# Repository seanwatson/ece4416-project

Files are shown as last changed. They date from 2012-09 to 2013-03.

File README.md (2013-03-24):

Engineering 4th Year Design Project:
====================================
Wireless Control System Utilizing Head Movement
===============================================

Description
-----------

As part of the engineering degree program at The University of Western Ontario
all students must complete an eight month design project in their final year
of study. For my project I developed a wireless control system that utilizes
head movement as the input to the system. The goal was to improve accessibility
for patients with limited or no control of their limbs.

For demonstration purposes the device was designed to control the movement and
clicking of a mouse on a computer screen. The device consists of a small,
wearable circuit that is concealed within a baseball cap and software running
on the computer. When the device is within wireless range of the computer it
automatically connects with the computer over bluetooth and
begins translating the user's head motions into mouse movements and clicks on the
screen.

For more information regarding the hardware designs please refer to the "hardware"
directory.

For more information regarding the software please refer to the "software"
directory.

Licenses
--------

The hardware designs in this work are licensed under a Creative Commons Attribution
3.0 license. The software in this work is licensed under the MIT license. Please refer
to the individual hardware and software directories for more information.

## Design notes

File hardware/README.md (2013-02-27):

Hardware
========

Overview
--------

The hardware consists of a microcontroller, a bluetooth module, an accelerometer, and power management circuitry:

###Microcontroller

- Atmel ATMega32U4
- Programming and debugging over USB port
- UART, ADC
- Deep sleep for power saving

###Bluetooth Module

- Roving Networks RN-42
- Communicates with MCU over UART
- Low power connect, SNIFF mode for power saving

###Accelerometer

- Analog Devices ADP3338
- 3 axis, analog outputs
- Very low power

###Power Management

- 850mA LiPo battery
- 3.3V linear regulator
- LiPo charge controller on board
- Charges over USB

Revisions
---------

The hardware for this project was developed over two revisions:

###Revision 1
- Designed as a development and debugging board for the purpose of easily diagnosing and fixing any bugs.
- Larger parts
- Debugging LEDs
- Debugging jumpers, etc. for the purpose of easily diagnosing and fixing any bugs.

###Revision 2
- Stripped down version of the circuit
- Lower power consumption
- Smaller physical size
- Smaller parts and no debugging features
- Can be concealed within a baseball cap

License
-------

These designs are licensed under a Creative Commons Attribution 3.0 license. See the
LICENSE.txt file for more details.

Acknowledgements
----------------

I'd like to thank the following companies who provided free or discount products and/or services
as part of this school project:

- Alberta Printed Circuits
- Analog Devices
- Atmel
- Microchip
- Roving Networks

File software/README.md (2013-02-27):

Software
=======

Overview
-------------

I have divided the software for this project into client and embedded software:

###Client

- Runs on the user's computer
- Searches for the device
- Automatically connects to the device when it was found
- Translates received commands into mouse movements and clicks on the screen

###Embedded

- Software running on the remote device
- Puts the device into a sleep state until a connection is found
- Once connected it continutally takes accelerometer readings
- Processes the accelerometer readings to determine motions
- Transmits the detected motions to the computer over bluetooth

Please refer to the individual "client" and "embedded" directories for more information.

License
-------------

The software for this work is licensed under an MIT license. Please refer to LICENSE.md for more details.

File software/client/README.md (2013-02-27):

Client
====

Files
-------

- **ece4416-project.py** - The main application for this project
- **bluetooth_connection.py** - Manages the bluetooth communication between the computer and the device
- **motion_handler.py** - Translates the received "motion codes" into mouse movements and clicks
- **motion.py** - Different motions that can be detected by the device
- **mouse_movement.py** - Different mouse actions that can be preformed when a motion is detected

Dependencies
-------------

- python-pybluez (bluetooth socket handling)
- python-pymouse (mouse movement and clicking)

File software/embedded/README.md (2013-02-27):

Embedded
====

Files
-------

- **ece4416_embedded** - The main embedded code
- **libraries** - Additional code for the project to help with accelerometer and motion handling. See the directory for information about the individual libraries
- **bluetooth_loader** - A program that quickly configures the bluetooth module to the settings used by this project
- **eeprom_loader** - Loads the EEPROM with known calibration values
- **serial_forwarder** - Forwards serial data from bluetooth to USB and USB to bluetooth. Used for debugging
- **accel_tester** - Used to print a stream of accelerometer readings to the screen. Used for debugging
- **comm\_handler\_test** - Program for testing the functionality of the communication handler

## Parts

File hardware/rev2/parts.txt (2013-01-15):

Partlist

Exported from sw-4416-project-v2.sch at 13-01-15 9:42 AM

EAGLE Version 6.2.0 Copyright (c) 1988-2012 CadSoft

Assembly variant: 

Part     Value                    Device                   Package             Library    Sheet

C1       0.1u                     CAP0603-CAP              0603-CAP            SparkFun   1
C2       0.1u                     CAP0603-CAP              0603-CAP            SparkFun   1
C3       0.1u                     CAP0603-CAP              0603-CAP            SparkFun   1
C4       1u                       CAP0603-CAP              0603-CAP            SparkFun   1
C5       1u                       CAP0603-CAP              0603-CAP            SparkFun   1
C6       22p                      CAP0603-CAP              0603-CAP            SparkFun   1
C7       22p                      CAP0603-CAP              0603-CAP            SparkFun   1
C8       4.7u                     CAP0603-CAP              0603-CAP            SparkFun   1
C9       4.7u                     CAP0603-CAP              0603-CAP            SparkFun   1
C10      4.7u                     CAP0603-CAP              0603-CAP            SparkFun   1
J1       CON_HEADER_PRG_AVR_ICSP" CON_HEADER_PRG_AVR_ICSP" HEADER_PRG_2X03_SMD dp_devices 1
JP1                               JUMPER-2PTH              1X02                SparkFun   1
L1                                INDUCTOR0805             0805                SparkFun   1
LED1                              LED0603                  LED-0603            SparkFun   1
R1       22                       RESISTOR0603-RES         0603-RES            SparkFun   1
R2       22                       RESISTOR0603-RES         0603-RES            SparkFun   1
R3       2k                       RESISTOR0603-RES         0603-RES            SparkFun   1
R4       10k                      RESISTOR0603-RES         0603-RES            SparkFun   1
R5       1M                       RESISTOR0603-RES         0603-RES            SparkFun   1
R6       330                      RESISTOR0603-RES         0603-RES            SparkFun   1
S1                                SWITCH-SPST-SMD-A        SWITCH-SPST-SMD-A   SparkFun   1
U$1      ATMEGA32U4QFN            ATMEGA32U4QFN            QFN-44              SparkFun   1
U$2      BLUETOOTH-RN41"          BLUETOOTH-RN41"          RN41                SparkFun   1
U$3      CRYSTAL_SMT              CRYSTAL_SMT              CRYSTAL-SMD-5X3     SparkFun   1
U1       ADXL335                  ADXL335                  LFCSP-16            SparkFun   1
U2       MCP73831                 MCP73831                 SOT23-5             SparkFun   1
VREG1    ADP3338                  VREG_3PINS-SOT-223       SOT-223             dp_devices 1
X1       USB-MICROB               USB-MICROB               USB-MICROB          SparkFun   1

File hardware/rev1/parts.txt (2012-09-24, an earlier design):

Partlist

Exported from sw-4416-project-v1.sch at 12-09-24 6:30 PM

EAGLE Version 6.2.0 Copyright (c) 1988-2012 CadSoft

Assembly variant: 

Part     Value           Device             Package           Library    Sheet

C1       0.1uF           CAP0603-CAP        0603-CAP          SparkFun   1
C2       0.1uF           CAP0603-CAP        0603-CAP          SparkFun   1
C3       0.1uF           CAP0603-CAP        0603-CAP          SparkFun   1
C4       4.7uF           CAP0603-CAP        0603-CAP          SparkFun   1
C5       4.7uF           CAP0603-CAP        0603-CAP          SparkFun   1
C6       4.7uF           CAP0603-CAP        0603-CAP          SparkFun   1
C7       4.7uF           CAP0603-CAP        0603-CAP          SparkFun   1
C8       4.7uF           CAP0603-CAP        0603-CAP          SparkFun   1
C9       4.7uF           CAP0603-CAP        0603-CAP          SparkFun   1
C10      22pF            CAP0603-CAP        0603-CAP          SparkFun   1
C11      22pF            CAP0603-CAP        0603-CAP          SparkFun   1
C12      1uF             CAP0603-CAP        0603-CAP          SparkFun   1
C13      1uF             CAP0603-CAP        0603-CAP          SparkFun   1
CN1                      JST_2PIN-SMT-RA    JST-PH-2-SMT-RA   adafruit   1
IC1      MCP73831        MCP73831           SOT23-5           SparkFun   1
ISP1     AVRISP-6        AVRISP-6           AVRISP            adafruit   1
JP1      Vcc             JUMPER-2PTH        1X02              SparkFun   1
JP2      VUSB            JUMPER-2PTH        1X02              SparkFun   1
JP3      3.3V            JUMPER-2PTH        1X02              SparkFun   1
JP4      GND             JUMPER-2PTH        1X02              SparkFun   1
JP5      AREF            JUMPER-2PTH        1X02              SparkFun   1
JP6      UART            JUMPER-2PTH        1X02              SparkFun   1
JP7      USB             JUMPER-2PTH        1X02              SparkFun   1
JP8      JUMPER-3PTH     JUMPER-3PTH        1X03              SparkFun   1
L1                       INDUCTOR0805       0805              SparkFun   1
LED1     Red             LED0603            LED-0603          SparkFun   1
LED2     Green           LED0603            LED-0603          SparkFun   1
LED3     Green           LED0603            LED-0603          SparkFun   1
LED4     Power           LED0603            LED-0603          SparkFun   1
LED5     RX              LED0603            LED-0603          SparkFun   1
LED6     TX              LED0603            LED-0603          SparkFun   1
LED7     DBG0            LED0603            LED-0603          SparkFun   1
LED8     DBG1            LED0603            LED-0603          SparkFun   1
R1       330             RESISTOR0603-RES   0603-RES          SparkFun   1
R2       10K             RESISTOR0603-RES   0603-RES          SparkFun   1
R3       330             RESISTOR0603-RES   0603-RES          SparkFun   1
R4       2k              RESISTOR0603-RES   0603-RES          SparkFun   1
R5       330             RESISTOR0603-RES   0603-RES          SparkFun   1
R6       330             RESISTOR0603-RES   0603-RES          SparkFun   1
R7       330             RESISTOR0603-RES   0603-RES          SparkFun   1
R8       22              RESISTOR0603-RES   0603-RES          SparkFun   1
R9       22              RESISTOR0603-RES   0603-RES          SparkFun   1
R10      330             RESISTOR0603-RES   0603-RES          SparkFun   1
R11      1M              RESISTOR0603-RES   0603-RES          SparkFun   1
R12      10K             RESISTOR0603-RES   0603-RES          SparkFun   1
R13      10K             RESISTOR0603-RES   0603-RES          SparkFun   1
R14      10K             RESISTOR0603-RES   0603-RES          SparkFun   1
R15      330             RESISTOR0603-RES   0603-RES          SparkFun   1
R16      330             RESISTOR0603-RES   0603-RES          SparkFun   1
R17      10K             RESISTOR0603-RES   0603-RES          SparkFun   1
S1       Power           SWITCH-SPST-SMD-A  SWITCH-SPST-SMD-A SparkFun   1
U$1      ADXL335         ADXL335            LFCSP-16          SparkFun   1
U$2      ATMEGA32U4-AU   ATMEGA32U4-AU      TQFP44            adafruit   1
U$3      BLUETOOTH-RN41" BLUETOOTH-RN41"    RN41              SparkFun   1
U1       ADP3338         VREG_3PINS-SOT-223 SOT-223           dp_devices 1
X1       USB-MICROB      USB-MICROB         USB-MICROB        SparkFun   1
Y1       16M             CRYSTALHC49US      HC49US            SparkFun   1

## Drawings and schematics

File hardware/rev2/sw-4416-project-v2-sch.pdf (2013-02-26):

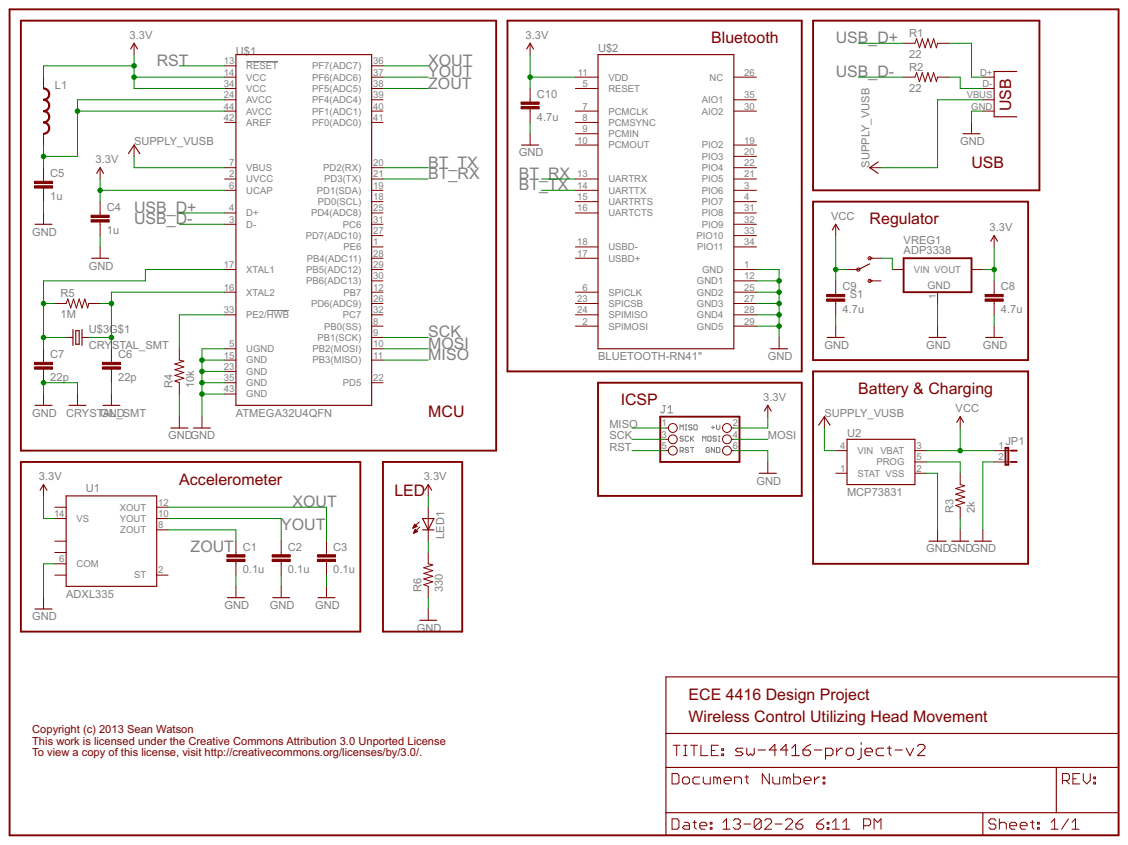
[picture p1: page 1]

ECE 4416 Design Project
Wireless Control Utilizing Head Movement

Copyright (c) 2013 Sean Watson This work is licensed under the Creative Commons Attribution 3.0 Unported License To view a copy of this license, visit http://creativecommons.org/licenses/by/3.0/.

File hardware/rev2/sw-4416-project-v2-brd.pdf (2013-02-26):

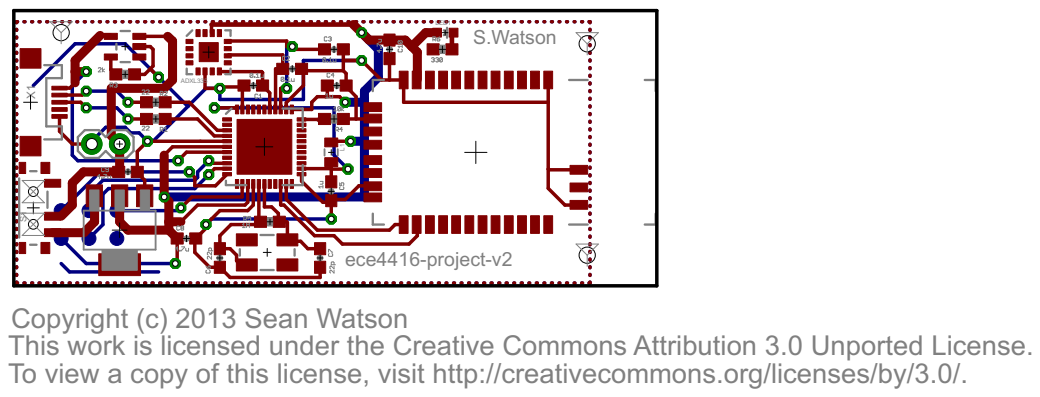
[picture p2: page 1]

Copyright (c) 2013 Sean Watson To view a copy of this license, visit http://creativecommons.org/licenses/by/3.0/. This work is licensed under the Creative Commons Attribution 3.0 Unported License.

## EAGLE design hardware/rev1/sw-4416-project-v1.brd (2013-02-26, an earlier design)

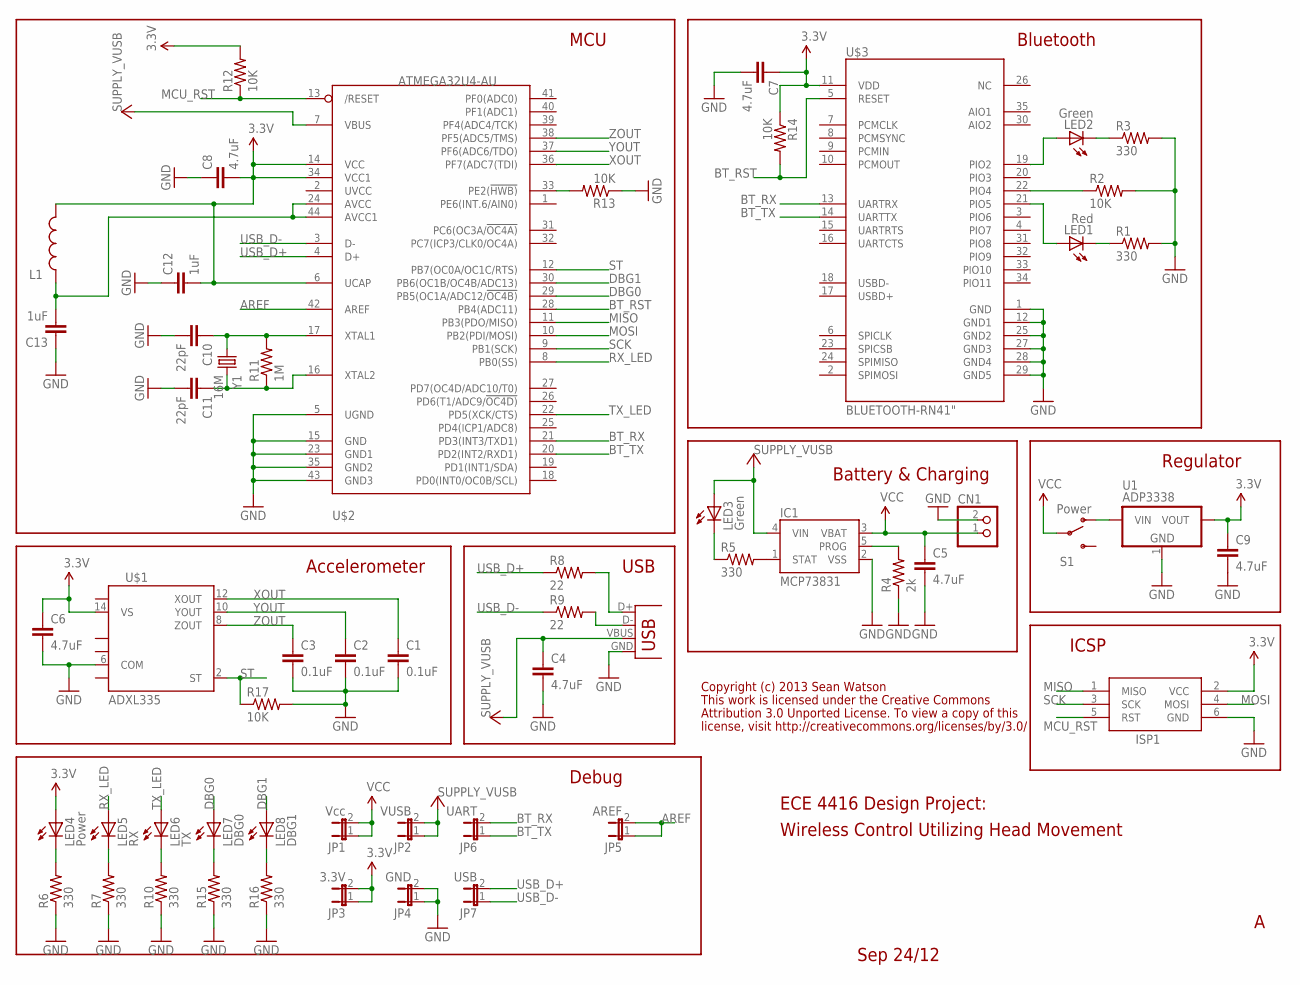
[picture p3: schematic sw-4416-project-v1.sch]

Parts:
C1, C2, C3: 0.1uF; 0603-CAP
C4, C5, C6, C7, C8, C9: 4.7uF; 0603-CAP
C10, C11: 22pF; 0603-CAP
C12, C13: 1uF; 0603-CAP
CN1: JST_2PIN-SMT-RA; JST-PH-2-SMT-RA
IC1: MCP73831; SOT23-5
ISP1: AVRISP-6; AVRISP
JP1: Vcc; 1X02
JP2: VUSB; 1X02
JP3: 3.3V; 1X02
JP4: GND; 1X02
JP5: AREF; 1X02
JP6: UART; 1X02
JP7: USB; 1X02
L1: INDUCTOR0805; 0805
LED1: Red; LED-0603
LED2, LED3: Green; LED-0603
LED4: Power; LED-0603
LED5: RX; LED-0603
LED6: TX; LED-0603
LED7: DBG0; LED-0603
LED8: DBG1; LED-0603
R1, R3, R5, R6, R7, R10, R15, R16: 330; 0603-RES
R2, R12, R13, R14, R17: 10K; 0603-RES
R4: 2k; 0603-RES
R8, R9: 22; 0603-RES
R11: 1M; 0603-RES
S1: Power; SWITCH-SPST-SMD-A
U1: ADP3338; SOT-223
U$1: ADXL335; LFCSP-16
U$2: ATMEGA32U4-AU; TQFP44
U$3: BLUETOOTH-RN41"; RN41
X1: USB-MICROB
Y1: 16M; HC49US

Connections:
3.3V: C6.1, C7.1, C8.2, C9.1, C12.2, ISP1.2 (VCC), JP3.1, JP3.2, L1.2, LED4.A, R12.2, R14.1, U1.2 (VOUT), U$1.14 (VS), U$2.6 (UCAP), U$2.14 (VCC), U$2.34 (VCC1), U$3.11 (VDD)
AREF: JP5.1, JP5.2, U$2.42 (AREF)
BT_RST: R14.2, U$2.28 (PB4(ADC11)), U$3.5 (RESET)
BT_RX: JP6.2, U$2.21 (PD3(INT3/TXD1)), U$3.13 (UARTRX)
BT_TX: JP6.1, U$2.20 (PD2(INT2/RXD1)), U$3.14 (UARTTX)
DBG0: LED7.A, U$2.29 (PB5(OC1A/ADC12/!OC4B))
DBG1: LED8.A, U$2.30 (PB6(OC1B/OC4B/ADC13))
GND: C1.2, C2.2, C3.2, C4.2, C5.2, C6.2, C7.2, C8.1, C9.2, C10.2, C11.2, C12.1, C13.1, CN1.2 (1), IC1.2 (VSS), ISP1.6 (GND), JP4.1, JP4.2, R1.2, R2.2, R3.2, R4.1, R6.1, R7.1, R10.1, R13.1, R15.1, R16.1, R17.2, U1.1 (GND), U$1.6 (COM), U$2.5 (UGND), U$2.15 (GND), U$2.23 (GND1), U$2.35 (GND2), U$2.43 (GND3), U$3.1 (GND), U$3.12 (GND1), U$3.25 (GND2), U$3.27 (GND3), U$3.28 (GND4), U$3.29 (GND5), X1.GND
MCU_RST: ISP1.5 (RST), R12.1, U$2.13 (/RESET)
MISO: ISP1.1 (MISO), U$2.11 (PB3(PDO/MISO))
MOSI: ISP1.4 (MOSI), U$2.10 (PB2(PDI/MOSI))
unnamed: LED2.C, R3.1
unnamed: LED1.C, R1.1
unnamed: R2.1, U$3.22 (PIO4)
unnamed: LED2.A, U$3.19 (PIO2)
unnamed: LED1.A, U$3.21 (PIO5)
unnamed: IC1.5 (PROG), R4.2
unnamed: IC1.1 (STAT), R5.2
unnamed: LED3.C, R5.1
unnamed: LED4.C, R6.2
unnamed: LED5.C, R7.2
unnamed: LED6.C, R10.2
unnamed: C10.1, R11.2, U$2.17 (XTAL1), Y1.1
unnamed: C11.1, R11.1, U$2.16 (XTAL2), Y1.2
unnamed: R8.2, X1.D+
unnamed: LED7.C, R15.2
unnamed: C13.2, L1.1, U$2.24 (AVCC), U$2.44 (AVCC1)
unnamed: LED8.C, R16.2
unnamed: R13.2, U$2.33 (PE2(!HWB))
unnamed: R9.2, X1.D-
RX_LED: LED5.A, U$2.8 (PB0(SS))
SCK: ISP1.3 (SCK), U$2.9 (PB1(SCK))
ST: R17.1, U$1.2 (ST), U$2.12 (PB7(OC0A/OC1C/RTS))
TX_LED: LED6.A, U$2.22 (PD5(XCK/CTS))
USB_D+: JP7.2, R8.1, U$2.4 (D+)
USB_D-: JP7.1, R9.1, U$2.3 (D-)
VCC: C5.1, CN1.1 (2), IC1.3 (VBAT), JP1.1, JP1.2, S1.2
VIN: S1.1 (O), U1.3 (VIN)
VUSB: C4.1, IC1.4 (VIN), JP2.1, JP2.2, LED3.A, U$2.7 (VBUS), X1.VBUS
XOUT: C1.1, U$1.12 (XOUT), U$2.36 (PF7(ADC7(TDI))
YOUT: C2.1, U$1.10 (YOUT), U$2.37 (PF6(ADC6/TDO))
ZOUT: C3.1, U$1.8 (ZOUT), U$2.38 (PF5(ADC5/TMS))

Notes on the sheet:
Accelerometer
Bluetooth
MCU
ECE 4416 Design Project:
Wireless Control Utilizing Head Movement
Battery & Charging
USB
Regulator
ICSP
Debug
Sep 24/12
Copyright (c) 2013 Sean Watson
This work is licensed under the Creative Commons
Attribution 3.0 Unported License. To view a copy of this
license, visit http://creativecommons.org/licenses/by/3.0/

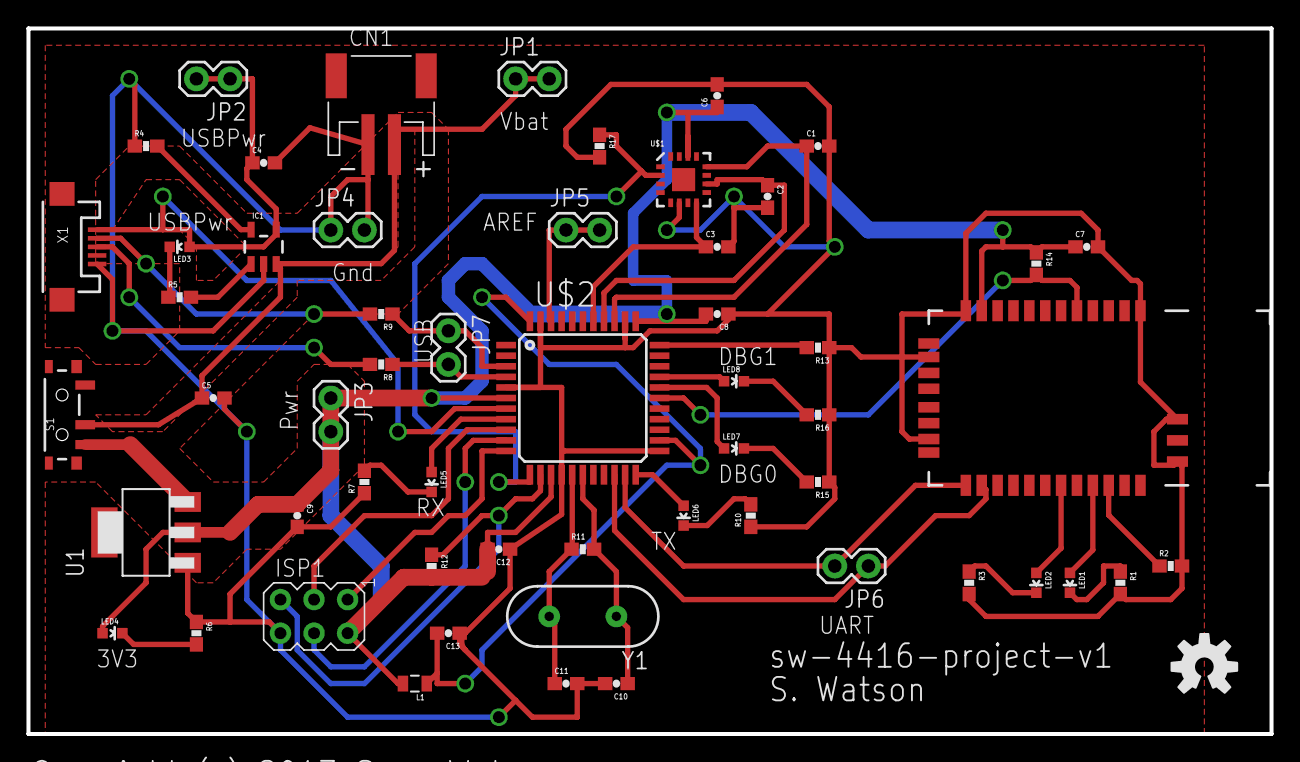
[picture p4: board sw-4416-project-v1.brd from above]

Board: 2 copper layers, 94.0 x 53.3 mm, 57 parts (0 on the bottom side), 42 nets.

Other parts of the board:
U$4: OSHW-LOGO-M

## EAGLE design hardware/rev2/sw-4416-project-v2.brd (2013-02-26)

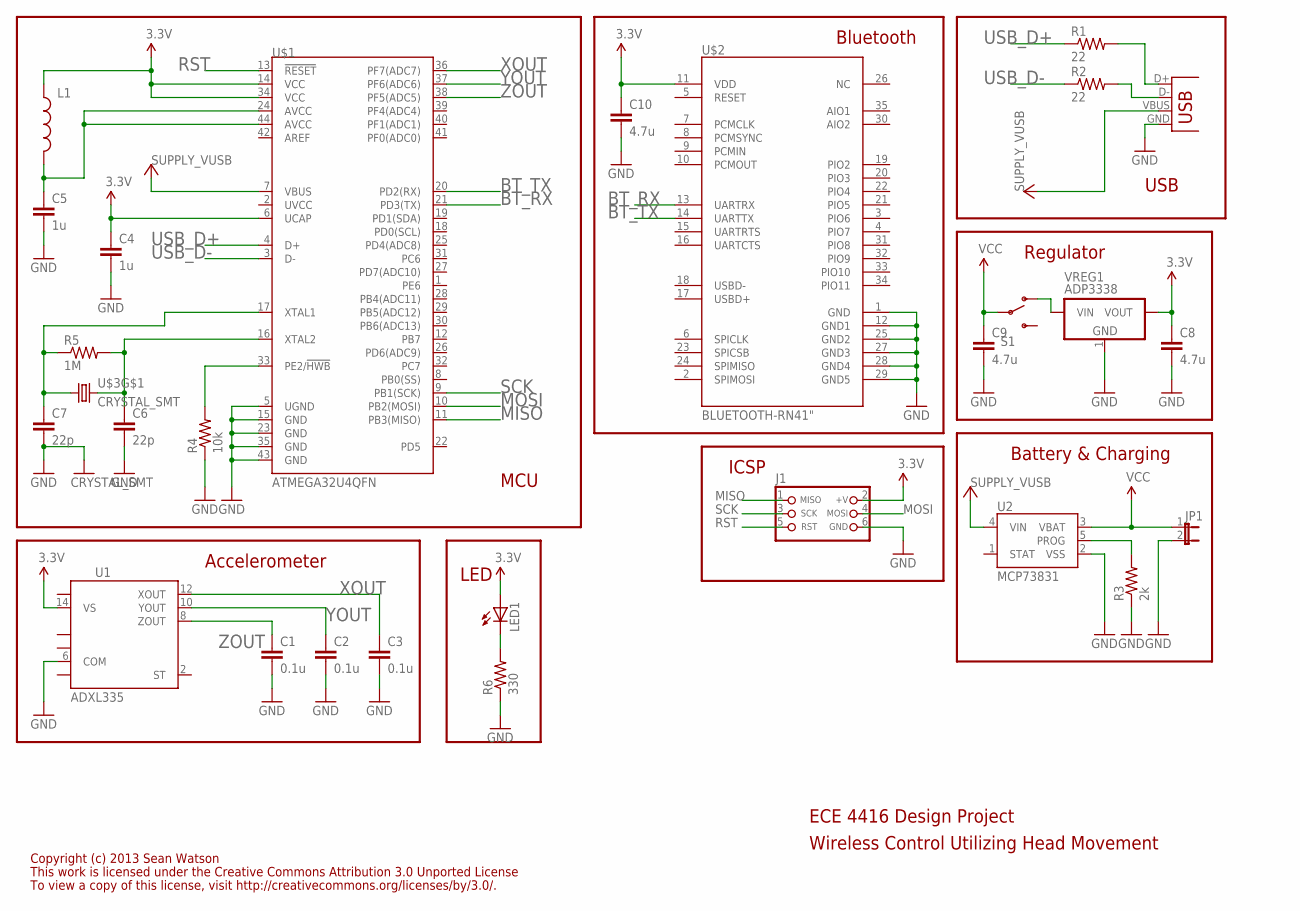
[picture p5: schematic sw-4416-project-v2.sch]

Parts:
C1, C2, C3: 0.1u; 0603-CAP
C4, C5: 1u; 0603-CAP
C6, C7: 22p; 0603-CAP
C8, C9, C10: 4.7u; 0603-CAP
J1: CON_HEADER_PRG_AVR_ICSP"; HEADER_PRG_2X03_SMD
JP1: JUMPER-2PTH; 1X02
L1: INDUCTOR0805; 0805
LED1: LED0603; LED-0603
R1, R2: 22; 0603-RES
R3: 2k; 0603-RES
R4: 10k; 0603-RES
R5: 1M; 0603-RES
R6: 330; 0603-RES
S1: SWITCH-SPST-SMD-A
U1: ADXL335; LFCSP-16
U2: MCP73831; SOT23-5
U$1: ATMEGA32U4QFN; QFN-44
U$2: BLUETOOTH-RN41"; RN41
U$3: CRYSTAL_SMT; CRYSTAL-SMD-5X3
VREG1: ADP3338; SOT-223
X1: USB-MICROB

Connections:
3.3V: C4.1, C8.1, C10.1, J1.2 (+V), L1.1, LED1.A, U1.14 (VS), U$1.6 (UCAP), U$1.14 (VCC), U$1.34 (VCC), U$2.11 (VDD), VREG1.2 (VOUT)
BT_RX: U$1.21 (PD3(TX)), U$2.13 (UARTRX)
BT_TX: U$1.20 (PD2(RX)), U$2.14 (UARTTX)
GND: C1.2, C2.2, C3.2, C4.2, C5.2, C6.2, C7.2, C8.2, C9.2, C10.2, J1.6 (GND), JP1.2, R3.1, R4.1, R6.1, U1.6 (COM), U2.2 (VSS), U$1.5 (UGND), U$1.15 (GND), U$1.23 (GND), U$1.35 (GND), U$1.43 (GND), U$2.1 (GND), U$2.12 (GND1), U$2.25 (GND2), U$2.27 (GND3), U$2.28 (GND4), U$2.29 (GND5), U$3.2 (GND), U$3.4 (GND), VREG1.1 (GND), X1.GND
MISO: J1.1 (MISO), U$1.11 (PB3(MISO))
MOSI: J1.4 (MOSI), U$1.10 (PB2(MOSI))
unnamed: S1.1 (O), VREG1.3 (VIN)
unnamed: R2.2, X1.D-
unnamed: R1.2, X1.D+
unnamed: R4.2, U$1.33 (PE2/!HWB)
unnamed: R3.2, U2.5 (PROG)
unnamed: C5.1, L1.2, U$1.24 (AVCC), U$1.44 (AVCC)
unnamed: C6.1, R5.2, U$1.16 (XTAL2), U$3.3 (2)
unnamed: C7.1, R5.1, U$1.17 (XTAL1), U$3.1
unnamed: LED1.C, R6.2
RST: J1.5 (RST), U$1.13 (!RESET)
SCK: J1.3 (SCK), U$1.9 (PB1(SCK))
USB_D+: R1.1, U$1.4 (D+)
USB_D-: R2.1, U$1.3 (D-)
VCC: C9.1, JP1.1, S1.2, U2.3 (VBAT)
VUSB: U2.4 (VIN), U$1.7 (VBUS), X1.VBUS
XOUT: C3.1, U1.12 (XOUT), U$1.36 (PF7(ADC7))
YOUT: C2.1, U1.10 (YOUT), U$1.37 (PF6(ADC6))
ZOUT: C1.1, U1.8 (ZOUT), U$1.38 (PF5(ADC5))

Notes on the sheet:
Regulator
USB
Battery & Charging
Bluetooth
ECE 4416 Design Project
Wireless Control Utilizing Head Movement
Accelerometer
MCU
ICSP
LED
Copyright (c) 2013 Sean Watson
This work is licensed under the Creative Commons Attribution 3.0 Unported License
To view a copy of this license, visit http://creativecommons.org/licenses/by/3.0/.

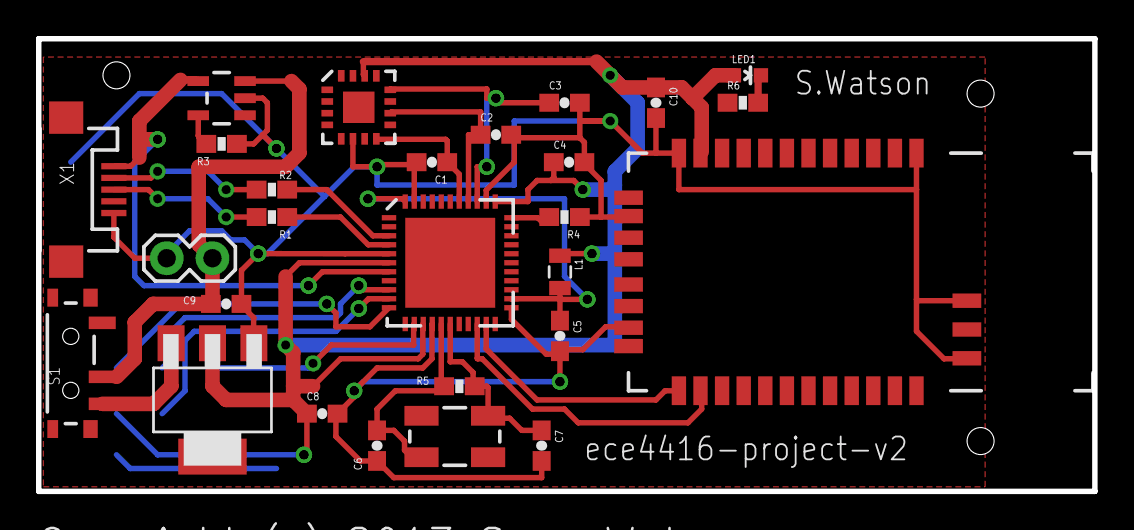
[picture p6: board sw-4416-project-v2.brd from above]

Board: 2 copper layers, 58.7 x 25.1 mm, 28 parts (1 on the bottom side), 24 nets.

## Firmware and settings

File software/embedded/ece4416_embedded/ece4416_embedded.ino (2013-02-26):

/*********************************************************
* 
* File:     ece4416_embedded.ino
* Author:   Sean Watson
* Date:     Feb 2013
*
* Description: Main embedded code for ECE 4416 project.
*              Manages the connection state and preforms
*              the necessary ADC for detecting motions
*
* Copyright (c) 2013 Sean Watson
* Licensed under the MIT license
*
**********************************************************/

// AVR libraries for sleeping
#include <avr/sleep.h>
#include <avr/power.h>
#include <avr/wdt.h>

// Arduino libraries
#include <EEPROM.h> // Used for reading calibrated angles from EEPROM

// Custom libraries
#include <Accelerometer.h>
#include <MotionHandler.h>
#include <Motion.h>
#include <CommHandler.h>

// Accelerometer pins
#define X_PIN   A0
#define Y_PIN   A1
#define Z_PIN   A2

// Sampling rates (ms)
#define ACCEL_RATE  10
#define SLEEP_RATE  1000

#define BT_BAUD 115200


// Setup peripherals
HardwareSerial* bluetooth = &Serial1;
Accelerometer accel(X_PIN, Y_PIN, Z_PIN);

// Setup handlers
MotionHandler motion_h(&accel, bluetooth);
CommHandler comm_h(&accel, bluetooth);

// Setup motions
Motion forwardMotion(1);
Motion rightMotion(2);
Motion backwardMotion(3);
Motion leftMotion(4);
Motion fastForwardMotion(5);
Motion fastRightMotion(6);
Motion fastBackwardMotion(7);
Motion fastLeftMotion(8);

void setup(){
  bluetooth->begin(BT_BAUD);// Start communication with BT module
  add_motions();            // Add motions to detect
  setup_wdt();              // Setup watchdog timer for sleep mode
  disable_periphs();        // Disable unused peripherals to save power
}

void loop(){
  
  // Process any incoming communications
  comm_h.process();
  
  // Check if the device is connected
  if(comm_h.connected()){
    
    // Connected, take a reading
    motion_h.process();

    // Limit sampling rate
    delay(ACCEL_RATE);
  }
  else{
    
    // Not connected, sleep
    sleep();

    // Stay awake for a period of time to detect communications
    delay(SLEEP_RATE);
  }  
}

// Disables unused peripherals for power saving
void disable_periphs(){
  power_spi_disable();
  power_timer2_disable();
  power_twi_disable();  
}

// Sets up the watchdog timer to wake the device from sleep
void setup_wdt(){
  
  // Clear the reset flag.
  MCUSR &= ~(1<<WDRF);
  
  // This allows WDT configuration for 4 clocks
  WDTCSR |= (1<<WDCE) | (1<<WDE);

  // Set new watchdog timeout
  //WDTCSR = 1<<WDP0 | 1<<WDP3;           // 8.0 seconds
  WDTCSR = 1<<WDP3;                     // 4.0 seconds
  //WDTCSR = 1<<WDP0 | 1<<WDP1 | 1<<WDP2; // 2.0 seconds
  //WDTCSR = 1<<WDP1 | 1<<WDP2;           // 1.0 second
  //WDTCSR = 1<<WDP0 | 1<<WDP2;           // 0.5 seconds 
  //WDTCSR = 1<<WDP2;                     // 0.25 seconds
  //WDTCSR = 1<<WDP0 | 1<<WDP1;           // 128 ms 
  //WDTCSR = 1<<WDP1;                     // 64 ms 
  //WDTCSR = 1<<WDP0;                     // 32 ms 
  
  // Enable the WDT interrupt
  WDTCSR |= _BV(WDIE);
}

// Adds motions to detect
void add_motions(){
  motion_h.add_motion(forwardMotion);
  motion_h.add_motion(rightMotion);
  motion_h.add_motion(backwardMotion);
  motion_h.add_motion(leftMotion);
  motion_h.add_motion(fastForwardMotion);
  motion_h.add_motion(fastRightMotion);
  motion_h.add_motion(fastBackwardMotion);
  motion_h.add_motion(fastLeftMotion);
}

// Puts the MCU into a power saving sleep mode
void sleep(){
  power_adc_disable();  // Disable the ADC for more power saving
  set_sleep_mode(SLEEP_MODE_PWR_DOWN);  // Complete power down
  sleep_enable();      // Enable sleep mode

  sleep_mode();        // Enter sleep (awakes on wdt and continues)
  
  sleep_disable();     // Disable sleep mode
  power_adc_enable();  // Re-enable the ADC
}

// Define WDT interrupt routine
ISR(WDT_vect){
  // Do nothing
}

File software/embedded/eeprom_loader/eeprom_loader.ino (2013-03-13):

/************************************************
*
* File:     eeprom_loader.ino
* Author:   Sean Watson
* Date:     Feb 2013
*
* Description: Loads the device's EEPROM with
*              known calibration values
*
* Copyright (c) 2013 Sean Watson
* Licensed under the MIT license
*
*************************************************/

#include <EEPROM.h>

//void setup(){
//  
// unsigned offset = 128;
// 
// // forward
// EEPROM.write(0, -70 + offset);
// EEPROM.write(1, 0 + offset);
// EEPROM.write(2, 70 + offset);
//
// // right
// EEPROM.write(3, -60 + offset);
// EEPROM.write(4, -25 + offset);
// EEPROM.write(5, -80 + offset);
//
// // backward
// EEPROM.write(6, -70 + offset);
// EEPROM.write(7, 0 + offset);
// EEPROM.write(8, -70 + offset);
//
// // left
// EEPROM.write(9, -70 + offset);
// EEPROM.write(10, 10 + offset);
// EEPROM.write(11, -80 + offset);
//
// // fast forward
// EEPROM.write(12, -55 + offset);
// EEPROM.write(13, 0 + offset);
// EEPROM.write(14, 55 + offset);
//
// // fast right
// EEPROM.write(15, -50 + offset);
// EEPROM.write(16, -36 + offset);
// EEPROM.write(17, -80 + offset);
//
// // fast backward
// EEPROM.write(18, -55 + offset);
// EEPROM.write(19, 0 + offset);
// EEPROM.write(20, -55 + offset);
//
// // fast left
// EEPROM.write(21, -60  + offset);
// EEPROM.write(22, 25  + offset);
// EEPROM.write(23, -80  + offset); 
//  
//}

void setup(){
  
 unsigned offset = 128;
 
 // forward
 EEPROM.write(0, 40 + offset);
 EEPROM.write(1, 12 + offset);
 EEPROM.write(2, 40 + offset);

 // right
 EEPROM.write(3, 20 + offset);
 EEPROM.write(4, 0 + offset);
 EEPROM.write(5, 20 + offset);

 // backward
 EEPROM.write(6, 5 + offset);
 EEPROM.write(7, 30 + offset);
 EEPROM.write(8, 30 + offset);

 // left
 EEPROM.write(9, 20 + offset);
 EEPROM.write(10, 40 + offset);
 EEPROM.write(11, 48 + offset);

 // fast forward
 EEPROM.write(12, 60 + offset);
 EEPROM.write(13, 2 + offset);
 EEPROM.write(14, 60 + offset);

 // fast right
 EEPROM.write(15, 15 + offset);
 EEPROM.write(16, -15 + offset);
 EEPROM.write(17, 20 + offset);

 // fast backward
 EEPROM.write(18, -12 + offset);
 EEPROM.write(19, 30 + offset);
 EEPROM.write(20, 32 + offset);

 // fast left
 EEPROM.write(21, 30  + offset);
 EEPROM.write(22, 48  + offset);
 EEPROM.write(23, 60  + offset); 
  
}


void loop(){
  
}

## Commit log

2012-09-23 Adding partially completed schematic
    [sw-4416-project-v1.sch]
2012-09-23 Added power circuitry
    [sw-4416-project-v1.sch]
2012-09-24 changing repo structure
    [sw-4416-project-v1.sch]
2012-09-24 removing old schematic
    [sw-4416-project-v1.sch]
2012-09-24 schematic version 1 completed
    [sw-4416-project-v1.brd, sw-4416-project-v1.sch]
2012-10-02 rev 1 board finished
    [sw-4416-project-v1.brd, sw-4416-project-v1.sch]
2013-01-02 testing accelerometer
2013-01-12 rev 2 board
    [ece4416-project-v2.brd, ece4416-project-v2.sch]
2013-01-12 working on embedded side code
    [sw-4416-project-v1.brd, sw-4416-project-v1.sch]
2013-01-12 cleaning up
    [ece4416-project-v2.brd, ece4416-project-v2.sch, sw-4416-project-v1.brd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]
2013-01-12 more cleaning
    [sw-4416-project-v2.brd, sw-4416-project-v2.sch]
2013-01-12 rev2 design done
    [sw-4416-project-v2.brd, sw-4416-project-v2.sch]
2013-01-15 second rev completed
    [sw-4416-project-v2.brd, sw-4416-project-v2.sch]
2013-02-23 made a calibration utility, added slow/fast motions
2013-02-26 open sourcing hardware and software
    [sw-4416-project-v1.brd, sw-4416-project-v1.sch, sw-4416-project-v2.brd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]
2013-03-13 calibrated with device in case
2013-03-20 wireless calibration without having to reboot done

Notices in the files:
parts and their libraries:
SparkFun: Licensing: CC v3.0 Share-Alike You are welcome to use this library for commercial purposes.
